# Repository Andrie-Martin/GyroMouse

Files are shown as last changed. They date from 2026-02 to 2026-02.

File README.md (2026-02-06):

# 🖱️ GyroMouse  
**A Bluetooth Low Energy (BLE) Air Mouse built with ESP32 and MPU6050**

GyroMouse is a custom-built **air mouse** that allows users to control a computer cursor and scrolling actions using **hand movements in mid-air**. Instead of relying on an optical sensor and a flat surface, this project uses an **inertial measurement unit (IMU)** and Bluetooth Low Energy to explore surface-free human–computer interaction.

This repository documents **how the project was designed, built, tested, and refined**, from the initial idea to a fully working prototype.

## 📖 Project Background

The idea behind GyroMouse started with a simple problem: traditional mice require a physical surface, which limits their use during presentations, smart TV navigation, and mobile setups. We wanted to create an input device that could work **anywhere**, relying only on hand motion.

After evaluating different approaches—wired, wireless, and gesture-based—we decided to design an **air mouse** that uses gyroscopic motion and Bluetooth connectivity while remaining compact and portable.

## 🧠 System Overview

GyroMouse consists of four main subsystems:

- **ESP32 microcontroller** – operates as a Bluetooth Low Energy Human Interface Device (HID)
- **MPU6050 IMU** – provides gyroscope and accelerometer data
- **Physical buttons** – left click, right click, and scroll-lock
- **Battery-powered system** – enables fully wireless operation

The ESP32 continuously reads motion data from the MPU6050 and translates it into mouse actions sent wirelessly to a computer.

## 🔄 Project Roadmap

Before any hardware was built, the entire workflow of the project was planned.

### Overall Development Flow
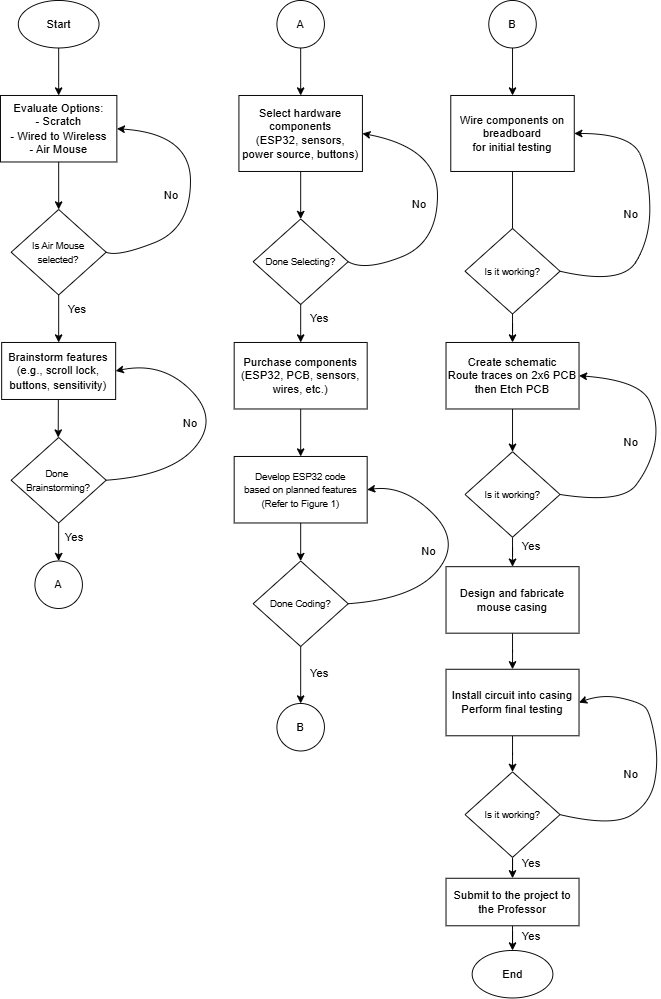
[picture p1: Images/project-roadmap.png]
Project Roadmap


The project followed these stages:
1. Idea evaluation and feature brainstorming  
2. Hardware component selection  
3. Initial breadboard testing  
4. Firmware development  
5. PCB layout and fabrication  
6. Final assembly and testing  

## ⚙️ Software and Progress Logic Flow

To define how the system behaves during operation, a detailed software and its implementation to the hardware (progress) flowchart was created.

### Software Flowchart
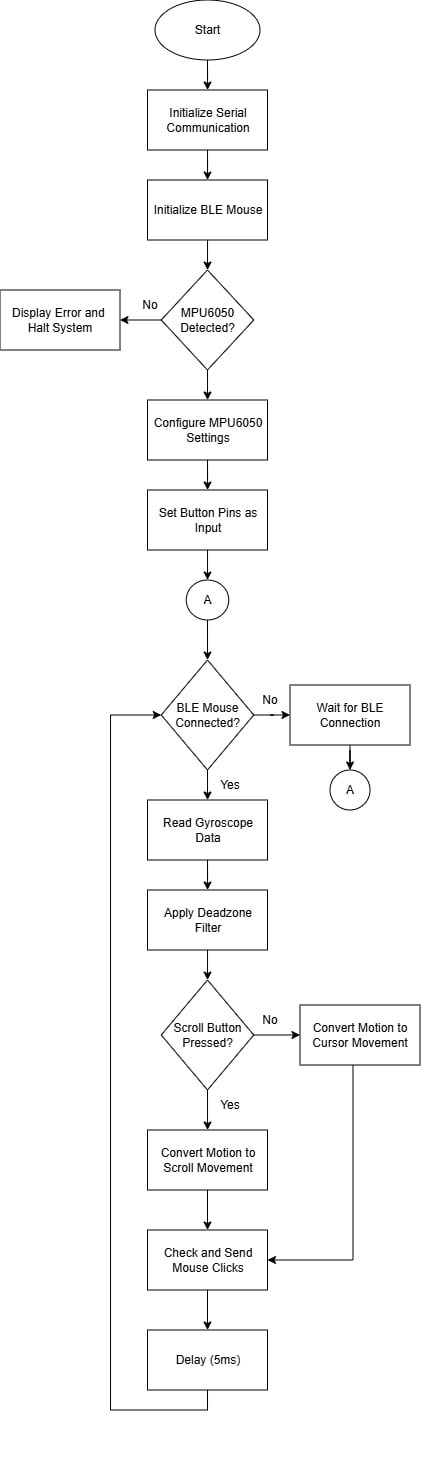
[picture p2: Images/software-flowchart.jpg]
Software Flowchart


The logic follows this sequence:
- Initialize serial communication  
- Initialize BLE mouse service  
- Check MPU6050 connection  
- Configure sensor settings and button pins  
- Wait for BLE connection  
- Continuously:
  - read gyroscope data  
  - apply deadzone filtering  
  - move cursor or scroll  
  - handle button presses  

## 🧪 Breadboard Testing
All components were first tested on a breadboard before transitioning to a permanent PCB to minimize errors.
Initial testing was performed using a breadboard to verify:
- Bluetooth connectivity  
- Gyroscope responsiveness  
- Cursor movement accuracy  
- Button functionality  

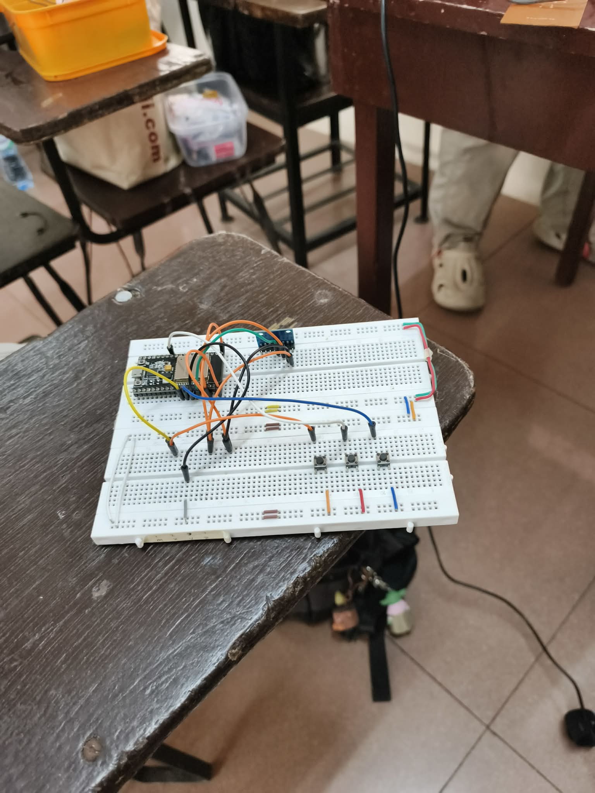
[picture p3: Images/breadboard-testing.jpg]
Breadboard Testing


This step helped identify and resolve issues early in the development process.

## 🧱 PCB Fabrication Process

PCB fabrication involved several manual steps:
1. Drawing the PCB layout  
2. Etching using ferric chloride  
3. Cleaning the board  
4. Drilling component holes  
5. Soldering components  

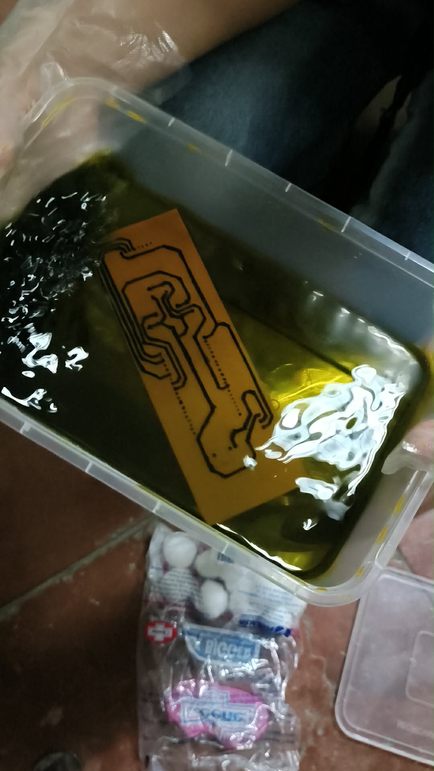
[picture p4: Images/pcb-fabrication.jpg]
PCB Fabrication


Manual PCB layout drawing was chosen after automated transfer methods produced inconsistent and unclear traces.

## ⚠️ Challenges Encountered

| Challenge | Solution |
|---|---|
| ESP32 not detected | Installed the correct ESP32 board package |
| MPU6050 issues | Used a compatible and stable sensor library |
| PCB transfer failed | Switched to manual PCB etching |
| Upload errors | Used ESP32 boot mode during flashing |
| Drilling precision | Used PCB-specific drill bits |

## ✅ Final Output

The completed **GyroMouse** functions as a fully wireless **Bluetooth Low Energy air mouse**, capable of smooth cursor control and scrolling **without requiring a physical surface**.  
The device demonstrates stable BLE connectivity, responsive motion tracking, and reliable button input.

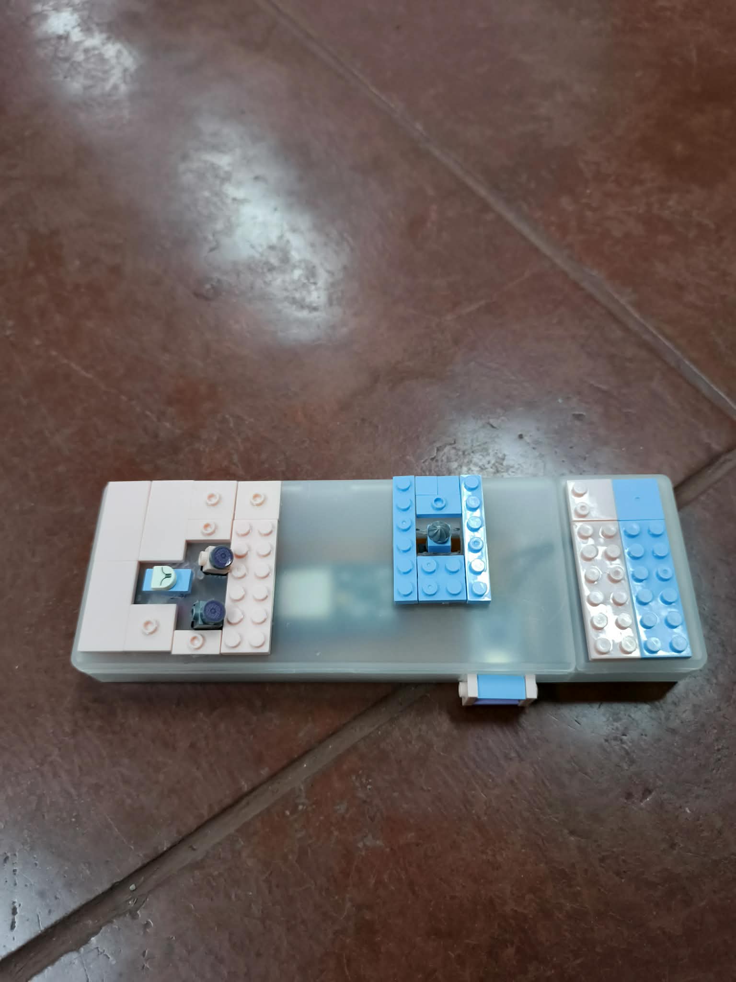
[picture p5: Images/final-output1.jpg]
Final Output

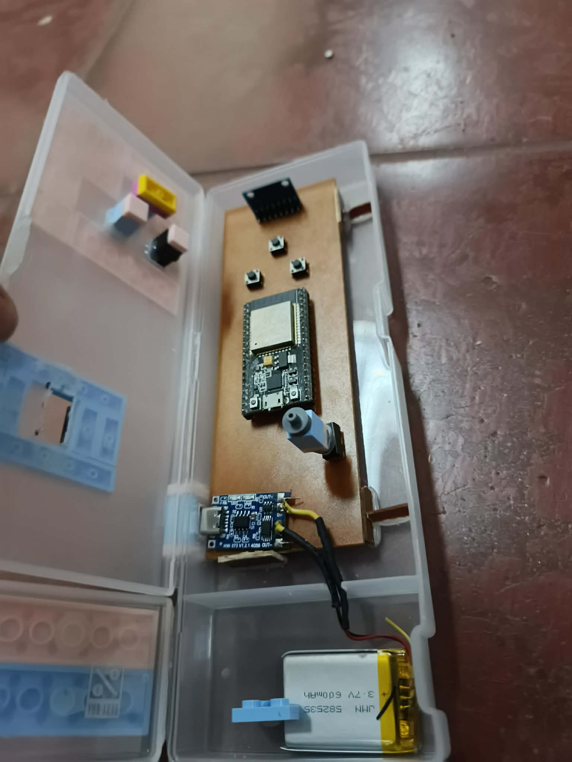
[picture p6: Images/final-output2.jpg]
Final Output


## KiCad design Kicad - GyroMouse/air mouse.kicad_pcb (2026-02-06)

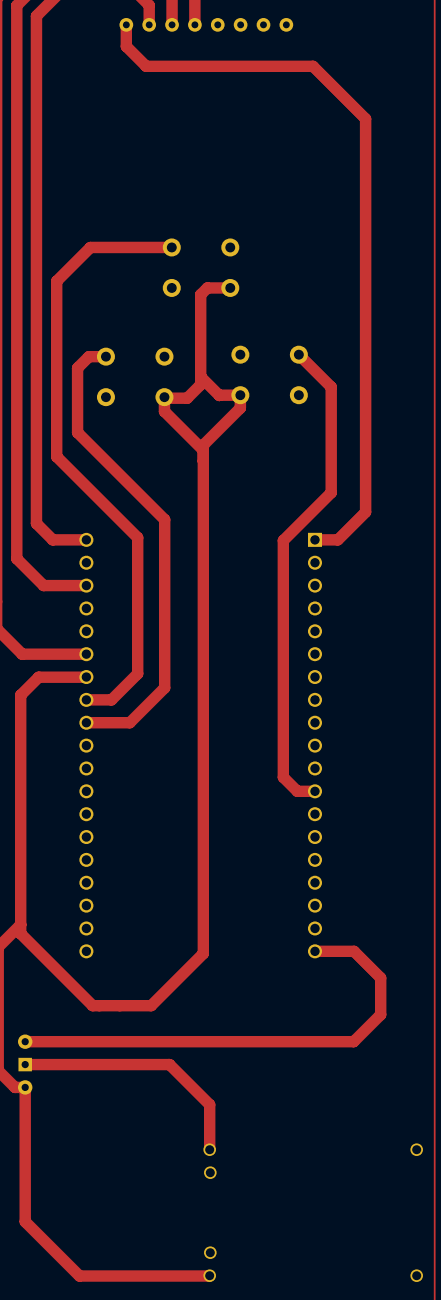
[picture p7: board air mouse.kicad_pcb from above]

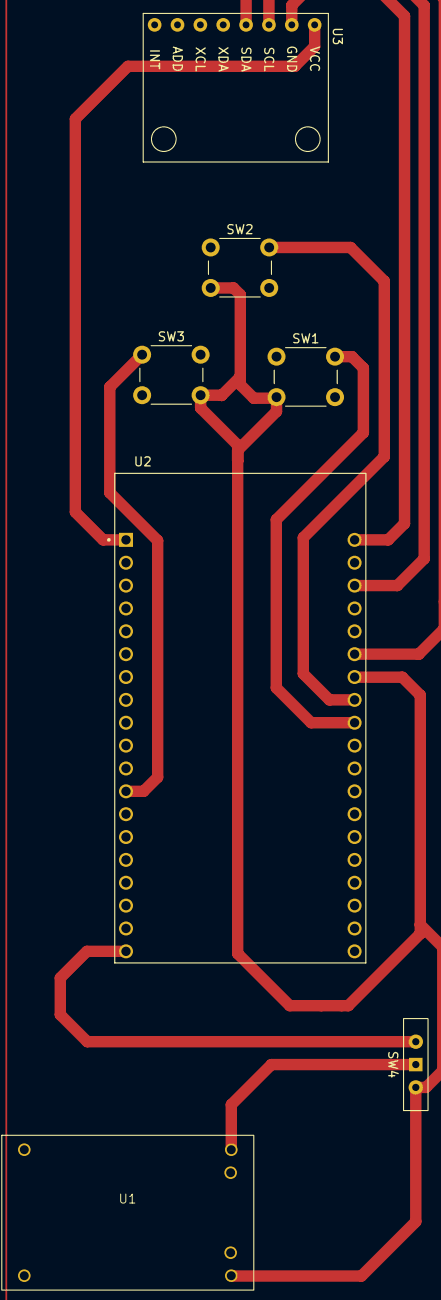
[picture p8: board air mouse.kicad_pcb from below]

Board: 2 copper layers, 7 parts (7 on the bottom side), 10 nets.

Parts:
SW1: SW_Left; SW_PUSH_6mm
SW2: SW_Scroll; SW_PUSH_6mm
SW3: SW_Right; SW_PUSH_6mm
SW4: SW_SPDT; SW_Slide-03_Wuerth-WS-SLTV_10x2.5x6.4_P2.54mm
U1: TP4056 Li-Ion Charger; TP4056 Customized
U2: ESP32-DEVKITC-32D; MODULE_ESP32-DEVKITC-32D
U3: module_mpu6050

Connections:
GND: SW1.2, SW2.2, SW3.2, SW4.2 (A), U1.4 (OUT-), U2.J3-7 (GND2)
INPUT: U2.J2-1 (3V3), U3.1 (VCC)
unnamed: SW4.1 (B), U1.3 (OUT+)
unnamed: SW4.3 (C), U2.J2-19 (EXT_5V)
unnamed: U2.J3-1 (GND3), U3.2 (GND)
unnamed: SW3.1, U2.J2-12 (IO14)
unnamed: SW1.1, U2.J3-9 (IO18)
unnamed: SW2.1, U2.J3-8 (IO19)
unnamed: U2.J3-6 (IO21), U3.4 (SDA)
unnamed: U2.J3-3 (IO22), U3.3 (SCL)

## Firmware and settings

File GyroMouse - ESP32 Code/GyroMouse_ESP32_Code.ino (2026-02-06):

#include <BleMouse.h>
#include <Adafruit_MPU6050.h>
#include <Adafruit_Sensor.h>
#include <Wire.h>

BleMouse bleMouse("ESP32 BLE Mouse");
Adafruit_MPU6050 mpu;

// Button pin for scroll
#define SCROLL_PIN 19
#define LEFT_CLICK_PIN  14
#define RIGHT_CLICK_PIN 18

// Base sensitivity and threshold
float baseSensitivity = 9.5;  // Adjust for overall speed
float threshold = 0.02;   // Deadzone to avoid jitter

// Smooth scrolling variables
bool mouseLocked = false;  // Tracks whether the mouse is locked for scrolling
float accumulatedMovementX = 0.0;  // Tracks horizontal movement for scrolling
float accumulatedMovementY = 0.0;  // Tracks vertical movement for scrolling
float scrollSpeed = 2.0;  // Controls the sensitivity of the scrolling

void setup() {
  Serial.begin(115200);
  Serial.println("Starting BLE Mouse with MPU6050 (Simple Version)");

  // Start BLE
  bleMouse.begin();

  // Start MPU
  if (!mpu.begin()) {
    Serial.println("MPU6050 not found, check wiring!");
    while (1) delay(10);
  }

  // Configure MPU ranges
  mpu.setAccelerometerRange(MPU6050_RANGE_4_G);
  mpu.setGyroRange(MPU6050_RANGE_500_DEG);
  mpu.setFilterBandwidth(MPU6050_BAND_21_HZ);

  // Buttons as input with pullups
  pinMode(LEFT_CLICK_PIN, INPUT_PULLUP);
  pinMode(RIGHT_CLICK_PIN, INPUT_PULLUP);
  pinMode(SCROLL_PIN, INPUT_PULLUP);

  Serial.println("Setup complete, waiting for BLE connection...");
}

void loop() {
  if (bleMouse.isConnected()) {
    // --- MPU6050 Gyro Movement ---
    sensors_event_t a, g, temp;
    mpu.getEvent(&a, &g, &temp);

    // Raw gyro values directly
    float gyroX = g.gyro.x; // Roll
    float gyroY = g.gyro.y; // Pitch
    float gyroZ = g.gyro.z; // Yaw

    // Map gyro movement to cursor
    float moveX = gyroZ; // horizontal
    float moveY = gyroY; // vertical 

    // Deadzone filter
    if (fabs(moveX) < threshold) moveX = 0;
    if (fabs(moveY) < threshold) moveY = 0;

    // If mouse is locked, interpret movement as scrolling
    if (mouseLocked) {
      // Accumulate movement for scrolling
      accumulatedMovementY += moveY;  // vertical movement for scrolling

      // Smooth scrolling: gradually adjust speed based on accumulated movement
      if (fabs(accumulatedMovementY) >= threshold) {
        int scrollAmount = (int)(accumulatedMovementY * scrollSpeed);  // Adjust sensitivity based on movement
        bleMouse.move(0, 0, scrollAmount); // Scroll vertically
        accumulatedMovementY = 0;  // Reset accumulated movement after scrolling
      }
    } else {
      // Mouse movement for cursor (only if not locked)
      float speed = sqrt(moveX * moveX + moveY * moveY);
      float dynamicSensitivity = baseSensitivity * (1 + speed * 0.2);
      moveX *= dynamicSensitivity;
      moveY *= dynamicSensitivity + 2;

      // Apply scaling and move the mouse in the same direction as the movement
      if ((int)moveX != 0 || (int)moveY != 0) {
        bleMouse.move((int)moveX, (int)moveY);  // up and down of mouse
      }
    }

    // --- Button Actions ---
    if (digitalRead(LEFT_CLICK_PIN) == LOW) {
      bleMouse.press(MOUSE_LEFT);
    } else {
      bleMouse.release(MOUSE_LEFT);
    }

    if (digitalRead(RIGHT_CLICK_PIN) == LOW) {
      bleMouse.press(MOUSE_RIGHT);
    } else {
      bleMouse.release(MOUSE_RIGHT);
    }

    // Scroll Button: Lock Mouse when pressed
    if (digitalRead(SCROLL_PIN) == LOW) {
      if (!mouseLocked) {
        mouseLocked = true;  // Lock the mouse for scrolling
      }
    } else {
      mouseLocked = false;  // Unlock the mouse when the button is released
    }

    delay(5); // small delay for smoother control
  }
}
